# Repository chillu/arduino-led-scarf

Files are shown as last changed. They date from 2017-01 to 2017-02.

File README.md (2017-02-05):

# Arduino LED Scarf and Top Hat

## Overview

This art project was for [Kiwiburn](http://kiwiburn.com/) 2016 and 2017,
the regional Burning Man in New Zealand.

An Arduino Nano powers LEDs in a fully scarf and stylish top hat,
with buttons for mode controls.
Comes with click-based beat matching and various "drop modes"
for maximum awesomeness on electronic music.

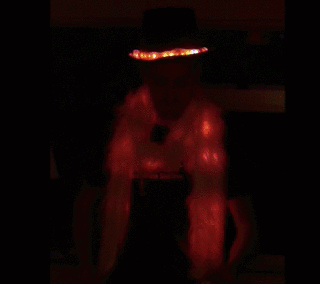
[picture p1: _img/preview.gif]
Preview


Check out more modes in the [full video](https://vimeo.com/202582452).

## Features

 * Beat button (button 1): Tap out beats, the patterns will adjust their speed
 * Brightness switcher (button 2): Three brightness levels, avoid blinding people in dark spaces
 * Mode switcher (button 3)
  * BPM: Trails emanating from the scarf centre, down both halves
  * Heartbeat: Trails following the human heart beat curve.
    Hooked up to the accelerometer, to show blue hues without movement, and red hues when dancing.
  * Plasma: Sine wave (single factor plasma) that moves up the strip
  * Juggle: Eight colored dots, weaving in and out of sync with each other
  * Sinelon: A colored dot sweeping back and forth, with fading trails
  * Confetti: Colourful, randomized dots in main palette colour.
    Drop mode switches to rainbow colours.
 * Palette switcher (long-press button 3): Three palettes built-in (ocean, lava, rainbow)
 * Drop mode (button 4): Brighter variations of the current mode (e.g. strobe mode)

## Software

You'll need [Platform.io](http://platformio.org/) to build this (or move some files around to build with the default Arduino IDE).

## Shopping List

 * 1x Arduino Nano
 * 150ish [Neopixel LEDs](https://learn.adafruit.com/adafruit-neopixel-uberguide/overview)
 * 2x 18650 battery (plus [holders](https://www.aliexpress.com/item/New-18650-Battery-Holder-Box-Case-Black-With-Wire-Lead-3-7V-Clip-5-Pcs-high/32580480645.html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))
 * 1x 3DOF accelerometer
 * 4x push buttons
 * 2x power switches
 * 1x [Veroboard](https://www.aliexpress.com/item/10-pcs-lot-universal-Stripboard-Veroboard-vero-Board-Single-Side-5x7cm-bakelite-universal-experiment-circuit-board/32321654013.html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) (optional)
 * 2x stereo headphone connectors, for power+data (optional)
 * 1x case (lunch box)
 * 1x 33yf/25V capacitor (optional, avoids sensor interference)

## Schematics

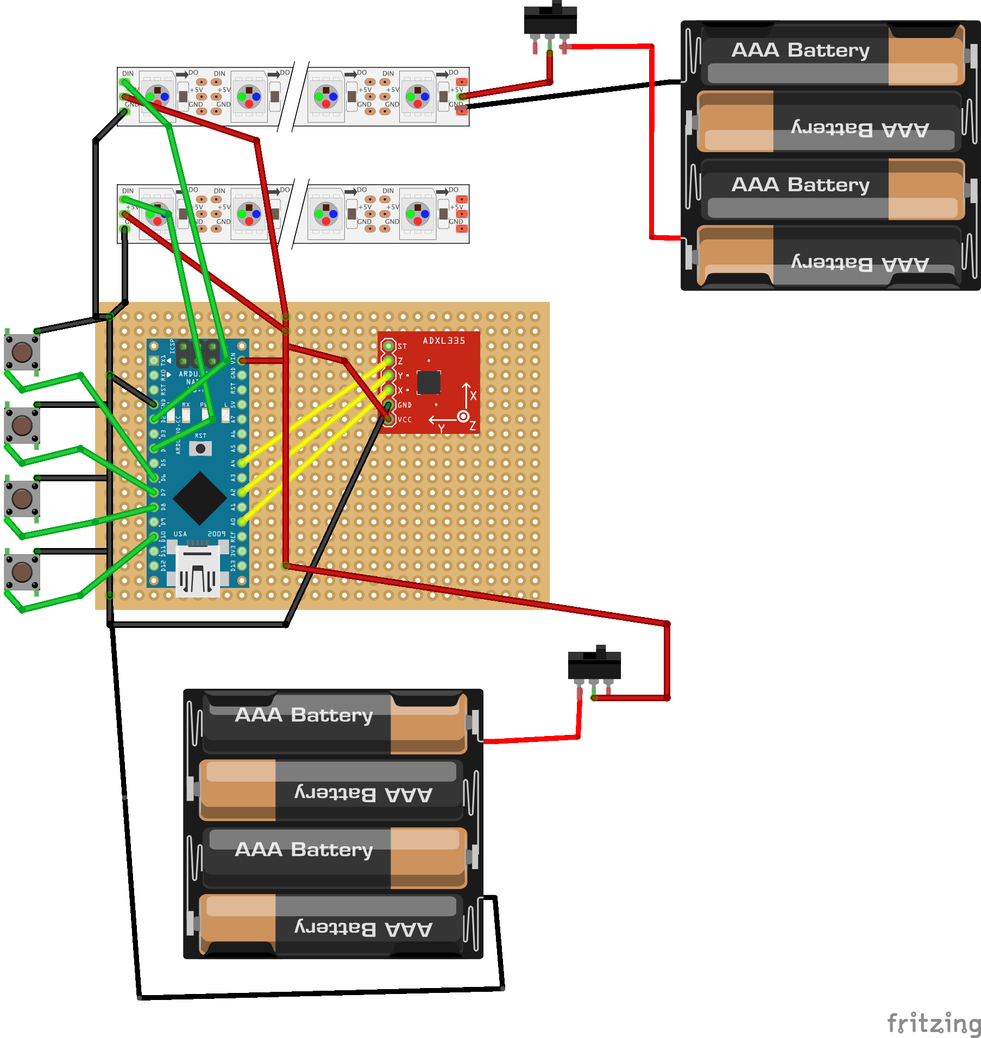
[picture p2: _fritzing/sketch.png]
Schematics


## Pictures

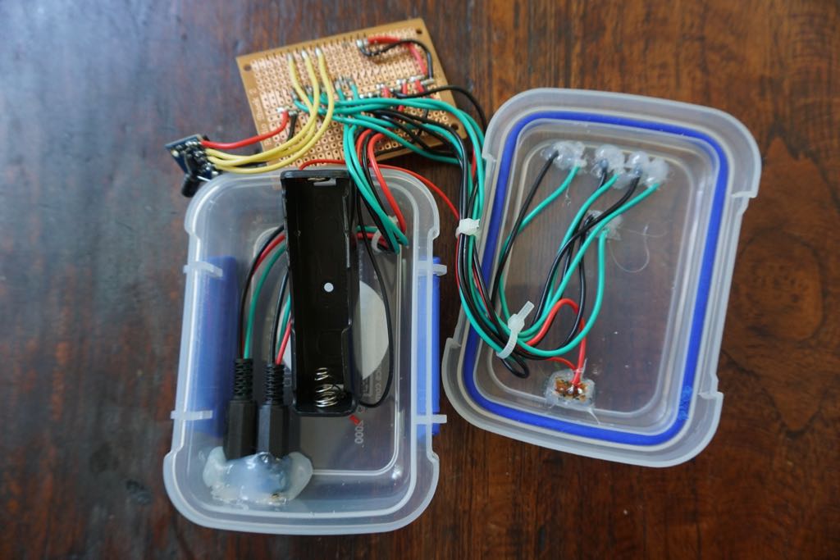
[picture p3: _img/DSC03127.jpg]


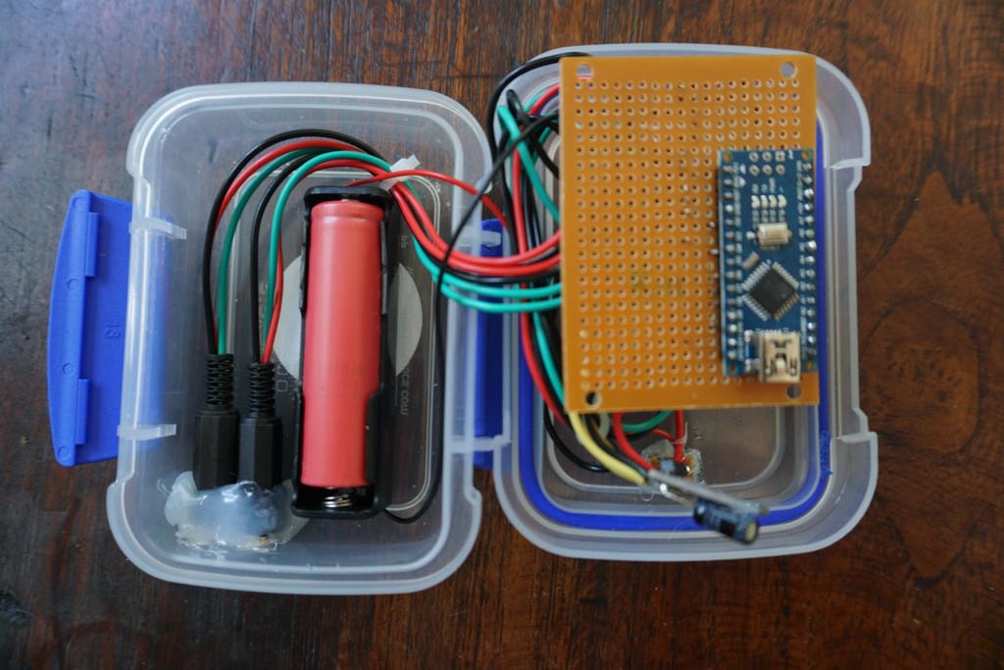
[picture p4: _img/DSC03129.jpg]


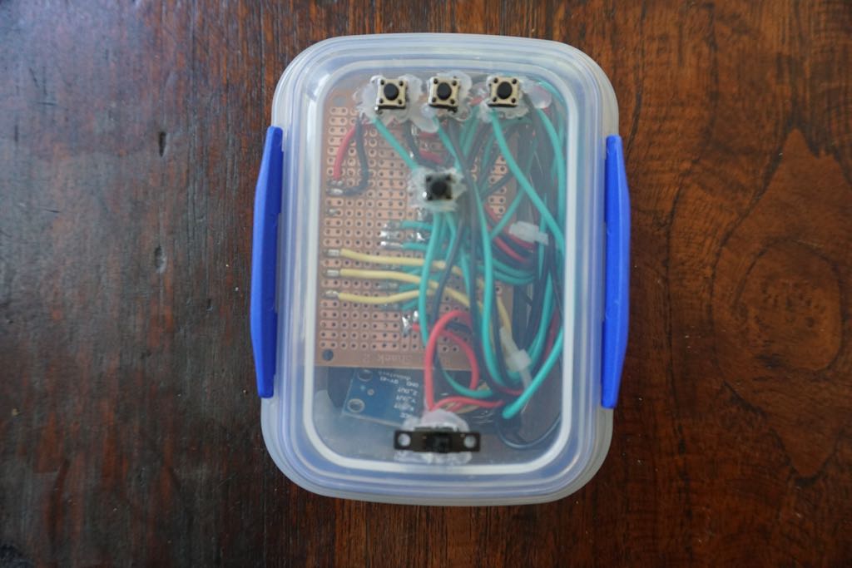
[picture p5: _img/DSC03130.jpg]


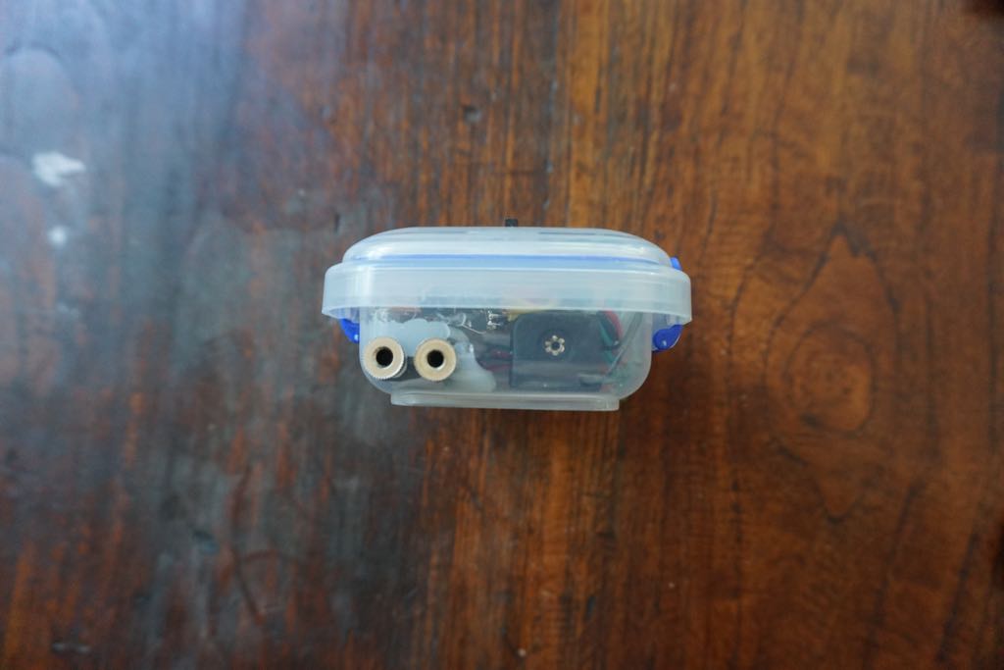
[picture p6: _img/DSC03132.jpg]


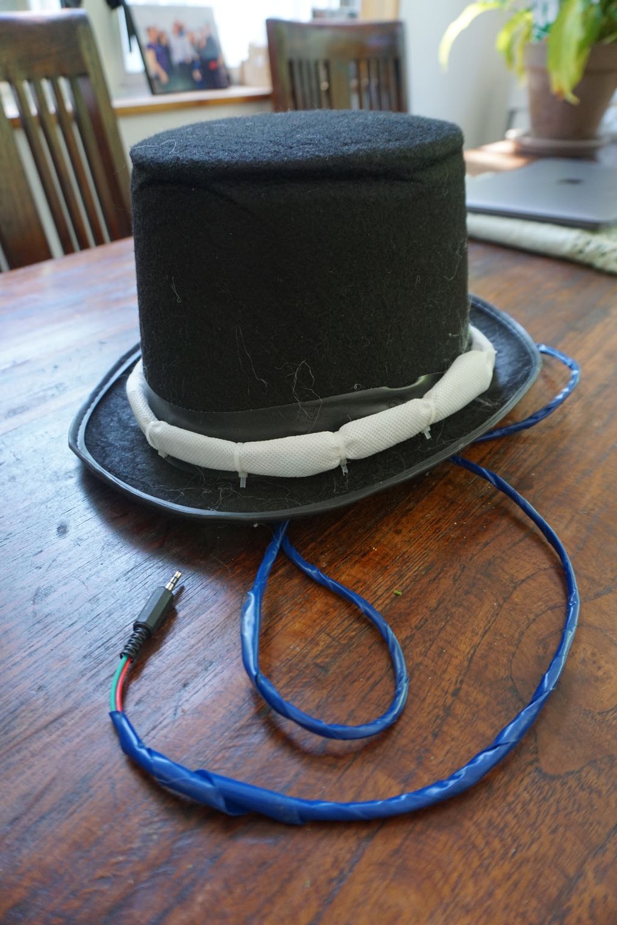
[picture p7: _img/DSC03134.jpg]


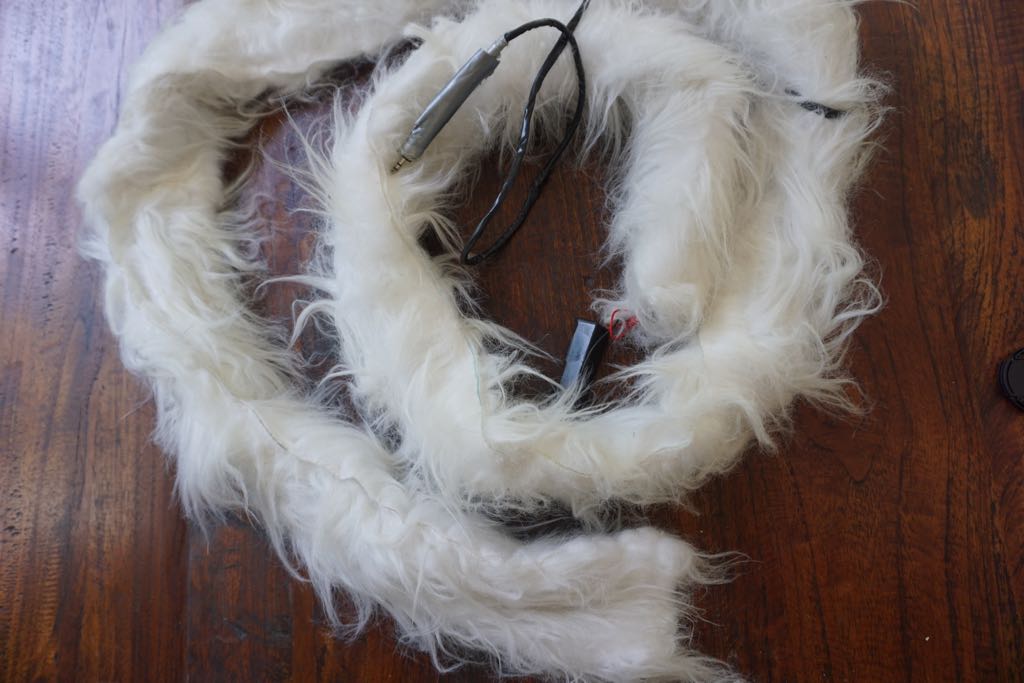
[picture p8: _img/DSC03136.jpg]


## Notes

Some hard learned lessons here, I've iterated on the concept,
and burned through three Nanos in the process :D

 * Adjust number of LEDs in main.cpp.
 * Add an extra battery at the end of the LED strip to ensure they get enough power (see [Powering Neopixels](https://learn.adafruit.com/adafruit-neopixel-uberguide/power))
 * A Veroboard will make it easier to solder the many connections,
   particularly with shared ground and power lines
 * The 3.5mm stereo audio jacks are used for power+data (NOT audio).
   It's a convenient and widely available form factor,
   but YYMV (JST connectors work just as well).
   More connections mean more points of failure,
   but it also makes the LED strips more reuseable.
 * With a max. draw of 500mAh (and a lot lower average),
   the batteries can power the scarf for around two nights of partying.
 * Keep cables long for the inevitable resolder (size your case accordingly)
 * Add some hot glue to make a waterproof case from a lunchbox

## Thanks

 * [bnolan](http://github.com/bnolan): For the hard work on the heartbeat visualisation
 * [sminnee](http://github.com/sminnee): For infinite resources in little electronic bits (nanos, connectors, buttons, you name it). Sam also wrote the bulk of the pattern list classes.
 * [stojg](http://github.com/stojg): For invaluable advice on how not to fuck up electronics (turns out you need capacitors!)
 * [caffeineinc](http://github.com/caffeineinc): For keeping my sanity, and the PARTY PANTS
 * [camp8bit](http://github.com/camp8bit): For a theme camp with great people

## LICENSE

Copyright 2017 Ingo Schommer

Redistribution and use in source and binary forms, with or without modification, are permitted provided that the following conditions are met:

1. Redistributions of source code must retain the above copyright notice, this list of conditions and the following disclaimer.

2. Redistributions in binary form must reproduce the above copyright notice, this list of conditions and the following disclaimer in the documentation and/or other materials provided with the distribution.

3. Neither the name of the copyright holder nor the names of its contributors may be used to endorse or promote products derived from this software without specific prior written permission.

THIS SOFTWARE IS PROVIDED BY THE COPYRIGHT HOLDERS AND CONTRIBUTORS "AS IS" AND ANY EXPRESS OR IMPLIED WARRANTIES, INCLUDING, BUT NOT LIMITED TO, THE IMPLIED WARRANTIES OF MERCHANTABILITY AND FITNESS FOR A PARTICULAR PURPOSE ARE DISCLAIMED. IN NO EVENT SHALL THE COPYRIGHT HOLDER OR CONTRIBUTORS BE LIABLE FOR ANY DIRECT, INDIRECT, INCIDENTAL, SPECIAL, EXEMPLARY, OR CONSEQUENTIAL DAMAGES (INCLUDING, BUT NOT LIMITED TO, PROCUREMENT OF SUBSTITUTE GOODS OR SERVICES; LOSS OF USE, DATA, OR PROFITS; OR BUSINESS INTERRUPTION) HOWEVER CAUSED AND ON ANY THEORY OF LIABILITY, WHETHER IN CONTRACT, STRICT LIABILITY, OR TORT (INCLUDING NEGLIGENCE OR OTHERWISE) ARISING IN ANY WAY OUT OF THE USE OF THIS SOFTWARE, EVEN IF ADVISED OF THE POSSIBILITY OF SUCH DAMAGE.

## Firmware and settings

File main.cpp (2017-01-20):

#include <Bounce2.h>
#include "FastLED.h"
#include <EEPROM.h>

// Digital PINs
#define LED_PIN_CH1 4
#define LED_PIN_CH2 2
#define MODE_BUTTON_PIN 6
#define BRIGHTNESS_BUTTON_PIN 8
#define BEAT_BUTTON_PIN 10

// Analog PINs
#define ACCELX_PIN 0
#define ACCELY_PIN 2
#define ACCELZ_PIN 4

// Other constants
#define BAUD_RATE 9600
#define NUM_LEDS_CH1 120
#define NUM_LEDS_CH2 29
#define FRAMES_PER_SECOND 30

// ui
int mode = 1;
int modeCount = 4;
Bounce modeButton;
Bounce brightnessButton;
Bounce beatButton;

// config
int currentBrightnessIndex = 1; // start with medium brightness
byte brightnesses[] = {30,60,90};
int staticBpm = 60; // in case no pulse is found
int pulseBpm = 0; // actually detected value
int maxBpm = 180; // avoids the system going crazy
byte beat[]  = {2,2,2,2,3,4,3,2,1,0,10,2,2,3,4,6,8,5,3,3,3,3}; // From http://ecg.utah.edu/img/items/Normal%2012_Lead%20ECG.jpg
byte beatLength = 22;
int beatMaxIntensity = 10; // max value in beat array
int movesPerBeat = 4;
int minMagnitude = 0;
int maxMagnitude = 50; // max difference between two magnitude measurements from accelerometer at which we show maxHue
int minBrightnessDivisor= 150; // lower = brighter
int maxBrightnessDivisor = 300; // higher = dimmer
int minHue = 160; // hue value under low motion, as defined through minMagnitude (from 0-255)
int maxHue = 255; // hue value under high motion, as defined through maxMagnitude (from 0-255)
int gainRatePerBeat = 6; // change towards new target magnitude
int decayRatePerBeat = 2; // move back towards minMagnitude
int sampleSize = 8; // smooth out accelerometer readings
int samplePerBeat = 1;

// state
int bpm = staticBpm;
byte bufr[NUM_LEDS_CH1];
byte offset = 0;
int currentMagnitude;
int targetMagnitude = maxMagnitude;
int adjustedMagnitude = maxMagnitude;

// pulse state
volatile boolean pulseFound = false; // "True" when User's live heartbeat is detected. "False" when not a "live beat". 
volatile boolean pulseBeatFound = false; // becomes true when Arduoino finds a beat.
volatile boolean hasPulse = false; // 

CRGB leds[2][NUM_LEDS_CH1];

void setup() { 
  FastLED.addLeds<NEOPIXEL, LED_PIN_CH1>(leds[0], NUM_LEDS_CH1);
  FastLED.addLeds<NEOPIXEL, LED_PIN_CH2>(leds[1], NUM_LEDS_CH2);
  
  Serial.begin(BAUD_RATE);

  pinMode(MODE_BUTTON_PIN, INPUT_PULLUP);
  modeButton.attach(MODE_BUTTON_PIN);
  modeButton.interval(50);

  pinMode(BRIGHTNESS_BUTTON_PIN, INPUT_PULLUP);
  brightnessButton.attach(BRIGHTNESS_BUTTON_PIN);
  brightnessButton.interval(50);

  pinMode(BEAT_BUTTON_PIN, INPUT_PULLUP);
  beatButton.attach(BEAT_BUTTON_PIN);
  beatButton.interval(50);

  updateModeFromEEPROM();
}

// other pattern config
uint8_t gHue = 0; // rotating "base color" used by many of the patterns

// Cycle mode in persistent memory on every on switch.
// More resilient against hardware failures than a button.
void updateModeFromEEPROM() {
  mode = EEPROM.read(0);
  if(!mode) {
    mode = 1;
  }
  mode = (mode % modeCount) + 1;
  
  EEPROM.write(0, mode);
}

void updateModeFromButton() {
  modeButton.update();
  int current = modeButton.read();
  if(modeButton.fell()) {
    mode = (mode % modeCount) + 1;
    Serial.print("mode: ");
    Serial.println(mode);
  }
}

void updateBrightnessFromButton() {
  brightnessButton.update();
  int current = brightnessButton.read();
  if(brightnessButton.fell()) {
    currentBrightnessIndex = ((currentBrightnessIndex + 1) % 3);
    Serial.print("currentBrightnessIndex: ");
    Serial.println(currentBrightnessIndex);
  }
}

void moveBuffer() {
  int i;
  byte c = (int) beat[offset] * 255 / beatMaxIntensity;
  int midPoint = NUM_LEDS_CH1/2;

  // Move current beat intensity from middle to beginning of strip (backward in buffer)
  bufr[midPoint - 1] = c;
  for (i=0;i<midPoint - 1;i++){
    bufr[i] = bufr[i+1];
  }

  // Move current beat intensity from middle to end of strip (forward in buffer)
  bufr[midPoint] = c;
  for (i=NUM_LEDS_CH1 - 1;i>midPoint;i--){
    bufr[i] = bufr[i-1];
  }
}

void draw() {
  int i;

  // Go from a cool color on low to a warm color on high activity
  int hue = map(
    adjustedMagnitude,
    minMagnitude,
    maxMagnitude,
    minHue,
    maxHue
  );

  // Lower magnitude means more brightness reduction
  int brightnessFactor = map(
    adjustedMagnitude,
    minMagnitude,
    maxMagnitude,
    maxBrightnessDivisor, 
    minBrightnessDivisor
  );
  
  // Channel 1
  for (i=0;i<NUM_LEDS_CH1;i++){
      leds[0][i] = CHSV(hue, bufr[i], bufr[i]/(brightnessFactor/100));
  }

  // Channel 2
  int halfPoint = (int)sizeof(bufr)/2;
  for (i=0;i<NUM_LEDS_CH2;i++){
      leds[1][i] = CHSV(hue, bufr[halfPoint], bufr[halfPoint]/(brightnessFactor/100));
  }
  
  FastLED.show();
}

int calcAdjustedMagnitude() {
  int newMagnitude = getMagnitude();
  int magnitudeDiff = abs(currentMagnitude - newMagnitude);
  
  // Get new target (smoothed out over a couple of readings)
  targetMagnitude = max(
    constrain(magnitudeDiff, minMagnitude, maxMagnitude), 
    targetMagnitude
  );
  
  // Slowly work towards new target (either increasing or decreasing)
  if(adjustedMagnitude <= targetMagnitude) {
    adjustedMagnitude = constrain(
      constrain(
        targetMagnitude + gainRatePerBeat, 
        minMagnitude,
        maxMagnitude
      ),
      minMagnitude, 
      maxMagnitude
    );
  } else {
    adjustedMagnitude = constrain(
      constrain(
        targetMagnitude - gainRatePerBeat, 
        minMagnitude,
        maxMagnitude
      ),
      minMagnitude, 
      maxMagnitude
    );
  }

  // Slowly decay max target
  targetMagnitude = targetMagnitude - decayRatePerBeat;
  targetMagnitude = constrain(
    targetMagnitude,
    minMagnitude, 
    maxMagnitude
  );

//  Serial.print(magnitudeDiff);
//  Serial.print("\t");
//  Serial.print(targetMagnitude);
//  Serial.print("\t");
//  Serial.print(adjustedMagnitude);
//  Serial.println();
  
  currentMagnitude = newMagnitude;
}

// Get a magnitude across all vectors.
// Smooth out result through a rolling average
int getMagnitude() {
  float avgMag = 0;
  for(int x = 0 ; x < sampleSize ; x++) {
    float aX = analogRead(ACCELX_PIN);
    float aY = analogRead(ACCELY_PIN);
    float aZ = analogRead(ACCELZ_PIN);

    float magnitude = sqrt((aX * aX) + (aY * aY) + (aZ * aZ));
    avgMag += magnitude;
  }
  avgMag /= sampleSize;
  
  return avgMag;
}

void loopHeartRate() {
  offset = (offset + 1) % beatLength;

  if (pulseFound == true && pulseBpm <= maxBpm) {
    bpm = pulseBpm;
  } else {
    bpm = staticBpm;
  }

  // TODO Fix BPM noise
  bpm = staticBpm;
  
  if (pulseBeatFound == true){
    pulseBeatFound = false;
  }

  int i;
  for (i=0;i<movesPerBeat;i++){
    // Delay in milliseconds. BPM are measured by minute, so divide accordingly.
    delay((float) 1 / (bpm * 60 * 1000) / beatLength / movesPerBeat);
    moveBuffer();
    draw();
  }

  // Measure only a few times per beat to avoid slowdowns
  if(offset % round(beatLength/samplePerBeat) == 0) {
    calcAdjustedMagnitude(); 
  }
}

void rainbow(int ledIndex, int num) 
{
  // FastLED's built-in rainbow generator
  fill_rainbow( leds[ledIndex], num, gHue, 7);
}

void rainbowWithGlitter(int ledIndex, int num) 
{
  // built-in FastLED rainbow, plus some random sparkly glitter
  rainbow(ledIndex, num);
  addGlitter(80, ledIndex, num);
}

void addGlitter( fract8 chanceOfGlitter, int ledIndex, int num) 
{
  if( random8() < chanceOfGlitter) {
    leds[ledIndex][ random16(num) ] += CRGB::White;
  }
}

void confetti(int ledIndex, int num) 
{
  // random colored speckles that blink in and fade smoothly
  fadeToBlackBy( leds[ledIndex], num, 10);
  int pos = random16(num);
  leds[ledIndex][pos] += CHSV( gHue + random8(64), 200, 255);
}

void sinelon(int ledIndex, int num)
{
  // a colored dot sweeping back and forth, with fading trails
  fadeToBlackBy( leds[ledIndex], num, 20);
  int pos = beatsin16(13,0,num);
  leds[ledIndex][pos] += CHSV( gHue, 255, 192);
}

void juggle(int ledIndex, int num) {
  // eight colored dots, weaving in and out of sync with each other
  fadeToBlackBy( leds[ledIndex], num, 20);
  byte dothue = 0;
  for( int i = 0; i < 8; i++) {
    leds[ledIndex][beatsin16(i+7,0,num)] |= CHSV(dothue, 200, 255);
    dothue += 32;
  }
}


void loop() { 
  updateModeFromButton();
  updateBrightnessFromButton();

  int brightness = brightnesses[currentBrightnessIndex];

  // Activate effect based on mode
  if(mode == 1) {
    // Bright pulse meter
    minBrightnessDivisor = 200;
    maxBrightnessDivisor = 400;
    loopHeartRate();
  } else if (mode == 2) {
    FastLED.setBrightness(brightness);
    confetti(0, NUM_LEDS_CH1);
    confetti(1, NUM_LEDS_CH2);
    FastLED.show();  
    FastLED.delay(1000/FRAMES_PER_SECOND); 
    EVERY_N_MILLISECONDS( 20 ) { gHue++; }
  } else if (mode == 3) {
    FastLED.setBrightness(brightness);
    sinelon(0, NUM_LEDS_CH1);
    sinelon(1, NUM_LEDS_CH2);
    FastLED.show();  
    FastLED.delay(1000/FRAMES_PER_SECOND); 
    EVERY_N_MILLISECONDS( 20 ) { gHue++; }
  } else if (mode == 4) {
    FastLED.setBrightness(brightness);
    juggle(0, NUM_LEDS_CH1);
    juggle(1, NUM_LEDS_CH2);
    FastLED.show();  
    FastLED.delay(1000/FRAMES_PER_SECOND); 
    EVERY_N_MILLISECONDS( 20 ) { gHue++; }
  }

}

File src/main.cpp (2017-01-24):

#include <Bounce2.h>
#include <FastLED.h>
// #include <EEPROM.h>

#define DEBUG

#ifdef DEBUG
  #define DEBUG_PRINT(msg) (Serial.println(msg))
#else
  #define DEBUG_PRINT(msg) ()
#endif

// Digital PINs
#define LED_PIN_CH1 4
#define LED_PIN_CH2 2
#define MODE_BUTTON_PIN 6
#define DROP_BUTTON_PIN 7
#define BRIGHTNESS_BUTTON_PIN 8
#define BEAT_BUTTON_PIN 10

// Analog PINs
#define ACCELX_PIN A0
#define ACCELY_PIN A2
#define ACCELZ_PIN A4

// Other constants
#define BAUD_RATE 9600
#define NUM_LEDS_CH0 120
#define NUM_LEDS_CH1 29
#define FRAME_LENGTH 33 // 30 fps
#define NUM_STATES 2
#define MAX_MILLIAMPS 500 // should run for ~8h on 2x2000maH 18650

#include <Pattern.h>
#include <PatternList.h>
#include <PatternState.h>
#include <PaletteList.h>

#include <Plasma.h>
#include <Juggle.h>
#include <Sinelon.h>
#include <Confetti.h>
#include <Heartbeat.h>
#include <Bpm.h>

#include <BrightnessControl.h>
#include <ModeControl.h>
#include <BeatControl.h>
#include <DropControl.h>
#include <AccellerationControl.h>

CRGB ledsCh0[NUM_LEDS_CH0];
PatternState stateCh0(NUM_LEDS_CH0, ledsCh0);

CRGB ledsCh1[NUM_LEDS_CH1];
PatternState stateCh1(NUM_LEDS_CH1, ledsCh1);

Heartbeat *heartbeat = new Heartbeat();
Pattern *patternItems[] = {
  new Bpm(),
  heartbeat,
  new Plasma(),
  new Juggle(),
  new Sinelon(),
  new Confetti()
};
PatternList patternList(6, patternItems);

CRGBPalette16 *paletteItems[] = {
  new CRGBPalette16(
    CRGB::Blue,
    CRGB::DarkBlue,
    CRGB::DarkBlue,
    CRGB::DarkBlue,
    CRGB::DarkBlue,
    CRGB::DarkBlue,
    CRGB::DarkBlue,
    CRGB::DarkBlue,
    CRGB::Blue,
    CRGB::DarkBlue,
    CRGB::SkyBlue,
    CRGB::SkyBlue,
    CRGB::LightBlue,
    CRGB::White,
    CRGB::LightBlue,
    CRGB::SkyBlue
  ),
  // Lava
  new CRGBPalette16(
    CRGB::Black,
    CRGB::Maroon,
    CRGB::Black,
    CRGB::Maroon,
    CRGB::DarkRed,
    CRGB::Maroon,
    CRGB::DarkRed,
    CRGB::DarkRed,
    CRGB::DarkRed,
    CRGB::Red,
    CRGB::Orange,
    CRGB::White,
    CRGB::Orange,
    CRGB::Red,
    CRGB::DarkRed,
    CRGB::Black
  ),
  // Rainbow
  new CRGBPalette16(
    0xFF0000, 0xD52A00, 0xAB5500, 0xAB7F00,
    0xABAB00, 0x56D500, 0x00FF00, 0x00D52A,
    0x00AB55, 0x0056AA, 0x0000FF, 0x2A00D5,
    0x5500AB, 0x7F0081, 0xAB0055, 0xD5002B
  )
};
PaletteList paletteList(3, paletteItems);


BrightnessControl brightnessControl(BRIGHTNESS_BUTTON_PIN);
ModeControl modeControl(MODE_BUTTON_PIN);
BeatControl beatControl(BEAT_BUTTON_PIN);
DropControl dropControl(DROP_BUTTON_PIN);
AccellerationControl accellerationControl(ACCELX_PIN, ACCELY_PIN, ACCELZ_PIN);

// See https://learn.adafruit.com/multi-tasking-the-arduino-part-1/using-millis-for-timing
long previousMillis = 0;

// // Cycle mode in persistent memory on every on switch.
// // More resilient against hardware failures than a button.
// void updateModeFromEEPROM() {
//   mode = EEPROM.read(0);
//   if(!mode) {
//     mode = 1;
//   }
//   mode = (mode % modeCount) + 1;
//
//   EEPROM.write(0, mode);
// }

void setup() {
  // Sanity delay
  delay(500);

  FastLED.addLeds<NEOPIXEL, LED_PIN_CH1>(ledsCh0, NUM_LEDS_CH0);
  FastLED.addLeds<NEOPIXEL, LED_PIN_CH2>(ledsCh1, NUM_LEDS_CH1);

  Serial.begin(BAUD_RATE);

  // https://github.com/FastLED/FastLED/wiki/Power-notes#managing-power-in-fastled
  FastLED.setMaxPowerInVoltsAndMilliamps(5,MAX_MILLIAMPS);

  brightnessControl.setup();
  FastLED.setBrightness(brightnessControl.getBrightness());

  modeControl.setup();

  beatControl.setup();

  dropControl.setup();

  stateCh0.palette = paletteList.curr();
  patternList.setState(0, &stateCh0);

  stateCh1.palette = paletteList.curr();
  patternList.setState(1, &stateCh1);

  // updateModeFromEEPROM();
}

void loop() {
  // Timing
  unsigned long currentMillis = millis();

  // Mode and Palette
  modeControl.update();
  if(modeControl.rose()) {
    if(modeControl.wasLongPress()) {
      CRGBPalette16 *palette = paletteList.next();
      stateCh0.palette = palette;
      stateCh1.palette = palette;
    } else {
      patternList.next();
    }
  }
  Pattern *currPattern = patternList.curr();

  // Beat
  beatControl.update();
  currPattern->setBpm(beatControl.getBpm());
  currPattern->setOnBeat(beatControl.onBeat());
  currPattern->setBeatProgress(beatControl.beatProgress());

  // Drop
  dropControl.update();
  currPattern->setIsDropping((dropControl.read() == LOW));

  // Accelleration
  int magnitude;
  EVERY_N_MILLISECONDS(100) {
    // Expensive calc, perform sparingly
    accellerationControl.update();
    magnitude = accellerationControl.getAdjustedMagnitude();
    heartbeat->setMagnitude(magnitude);
  }

  // Patterns
  int frameLength = currPattern->getFrameLength();
  // Should use EVERY_N_MILLISECONDS, but the C++ macro
  // can't seem to change values dynamically
  if(currentMillis - previousMillis > frameLength) {
    previousMillis = currentMillis;
    patternList.loop(0);

    // Brightness
    brightnessControl.update();
    FastLED.setBrightness(brightnessControl.getBrightness());

    FastLED.show();
  }

}

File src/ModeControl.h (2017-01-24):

#include <Bounce2.h>

class ModeControl {
  Bounce _button;
  int pin;
  unsigned long _millisAtPress = 0;
  int _longPressMillis = 500;
  bool _wasLongPress = false;

public:
  ModeControl(int _pin): pin(_pin)
  {
    // no-op
  }

  void setup()
  {
    pinMode(pin, INPUT_PULLUP);
    _button.attach(pin);
    _button.interval(50);
  }

  void update()
  {
    _button.update();
    if (_button.fell()) {
      _millisAtPress = millis();
    }
    if (_button.rose()) {
      _wasLongPress = ((millis() - _millisAtPress) > _longPressMillis);
      _millisAtPress = 0;
    }
  }

  bool fell()
  {
    return _button.fell();
  }

  bool rose()
  {
    return _button.rose();
  }

  /**
   * Was the last press a long one?
   */
  bool wasLongPress()
  {
    return _wasLongPress;
  }
};

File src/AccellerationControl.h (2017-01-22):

/**
 * Calculates a magnitude based on accellerometer reads.
 * Smooths out gains and losses to transition between different readings over time.
 *
 * The maxMagnitude value depends on the sensor and setup,
 * some sensors will send down more current based on the same amount of motion.
 * Adjust accordingly.
 */
class AccellerationControl {

  int xPin;
  int yPin;
  int zPin;
  int currentMagnitude;
  int minMagnitude = 0;
  int maxMagnitude = 40; // max difference between two magnitude measurements
  int gainRatePerBeat = 10; // change towards new target magnitude
  int decayRatePerBeat = 1; // move back towards minMagnitude
  int sampleSize = 8; // smooth out accelerometer readings
  int targetMagnitude = maxMagnitude;
  int adjustedMagnitude = maxMagnitude;

  /**
   * Get a magnitude across all vectors.
   * Smooth out result through a rolling average
   */
  int getRawMagnitude() {
    float avgMag = 0;
    for(int x = 0 ; x < sampleSize ; x++) {
      float aX = analogRead(xPin);
      float aY = analogRead(yPin);
      float aZ = analogRead(zPin);

      float magnitude = sqrt((aX * aX) + (aY * aY) + (aZ * aZ));
      avgMag += magnitude;

      // Serial.print(aX);
      // Serial.print(",");
      // Serial.print(aY);
      // Serial.print(",");
      // Serial.print(aZ);
      // Serial.println();
    }
    avgMag /= sampleSize;

    // Serial.println(avgMag);

    return avgMag;
  }

public:
  AccellerationControl(int _xPin, int _yPin, int _zPin):
    xPin(_xPin), yPin(_yPin), zPin(_zPin)
  {
    // no-op
  }

  void setup()
  {
  }

  void update()
  {
    int newMagnitude = getRawMagnitude();
    int magnitudeDiff = abs(currentMagnitude - newMagnitude);

    // Get new target (smoothed out over a couple of readings)
    targetMagnitude = max(
      constrain(magnitudeDiff, minMagnitude, maxMagnitude),
      targetMagnitude
    );

    // Slowly work towards new target (either increasing or decreasing)
    if(adjustedMagnitude <= targetMagnitude) {
      adjustedMagnitude = constrain(
        constrain(
          targetMagnitude + gainRatePerBeat,
          minMagnitude,
          maxMagnitude
        ),
        minMagnitude,
        maxMagnitude
      );
    } else {
      adjustedMagnitude = constrain(
        constrain(
          targetMagnitude - gainRatePerBeat,
          minMagnitude,
          maxMagnitude
        ),
        minMagnitude,
        maxMagnitude
      );
    }

    // Slowly decay max target
    targetMagnitude = targetMagnitude - decayRatePerBeat;
    targetMagnitude = constrain(
      targetMagnitude,
      minMagnitude,
      maxMagnitude
    );

  //  Serial.print(magnitudeDiff);
  //  Serial.print("\t");
  //  Serial.print(targetMagnitude);
  //  Serial.print("\t");
  //  Serial.print(adjustedMagnitude);
  //  Serial.println();

   currentMagnitude = newMagnitude;
  }

  int getAdjustedMagnitude()
  {
    return adjustedMagnitude;
  }

};

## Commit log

2016-01-24 Add cylon effect and LED debugging
2016-01-24 Fixed debug LED, only output when beat detected
2016-01-25 Set mode from EEPROM rather than button
2016-01-25 Improved magnitude impact on hue, cap max BPMs
    Also lower brightness to avoid interfering with sensor data too much
2016-01-25 Updated hardware pin assignments to new circuit
2017-01-20 Remove heartbeat control LED
2017-01-20 Make heartbeat peaks less intense to avoid sensor overload
2017-01-20 Removed sensor libs
2017-01-20 Removed heartbeat code, can't get sensor noise under control
2017-01-20 Added mode and brightness buttons
2017-01-20 Removed cylon mode since it interferes with mode button
    Working theory: Too much LED activation = too much noise in system (despite INPUT_PULLUP resistor),
    which means the mode button no longer works
2017-01-22 Refactored patterns to support multiple LED strips
    Reinstated patterns as classes
2017-01-22 Factored out mode control
    Not ideal, control should keep track of its mode state, and interact with EEPROM
2017-01-22 Remove led getters, performance optimisation
2017-01-22 Improved BPM matching in Heartbeat
    delay() is flawed, since it doesn't take into account the time it takes to *compute*,
    so in effect every delay is larger.
    [Heartbeat.h, main.cpp]
2017-01-22 Fixed accell to new (lower) sample rate
    [AccellerationControl.h, Heartbeat.h, main.cpp]
2017-01-22 Cap power usage
2017-01-23 Allow each pattern to influence frames, new BPM effect
2017-01-23 Palette switching support
2017-01-23 More patterns, fix return bug
    [main.cpp]
2017-01-23 Long press button logic for pattern switching
2017-01-24 Start with lowest brightness
    Safer in terms of low battery
2017-02-05 Fritzing sketch and more docs
    [sketch.fzz]
2017-02-05 Docs about accelerometer
